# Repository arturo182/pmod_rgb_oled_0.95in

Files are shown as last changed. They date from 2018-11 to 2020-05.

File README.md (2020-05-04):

# 0.95" OLED PMOD

A tiny color OLED!

Perfect solution if you need a small display with vivid, high-contrast 16-bit color. PMOD connector can be used with FPGA and MCU dev boards

The display itself is a 0.95" color OLED, the resolution is 96x64 RGB pixels.

The display is driven by the SSD1331 IC, you can control it with a 4-wire write-only SPI. The board only supports 3.3V logic.

Libraries exist to interface the PMOD:
- [Arduino library](https://github.com/adafruit/Adafruit-SSD1331-OLED-Driver-Library-for-Arduino)
- [CircuitPython library](https://github.com/adafruit/Adafruit_CircuitPython_SSD1331)

**Note: This module is not 5V-tolerant!**

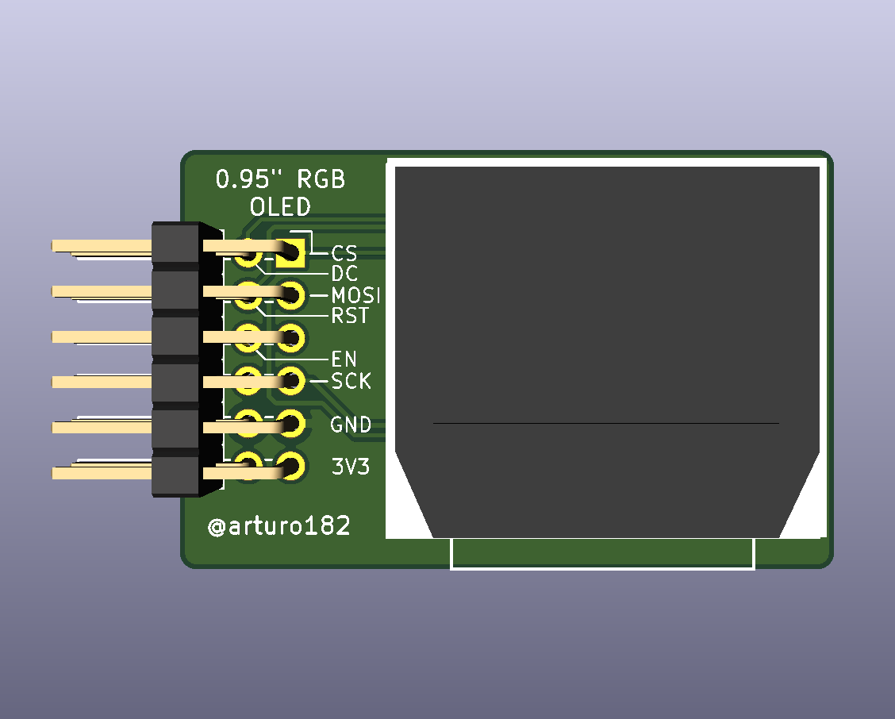
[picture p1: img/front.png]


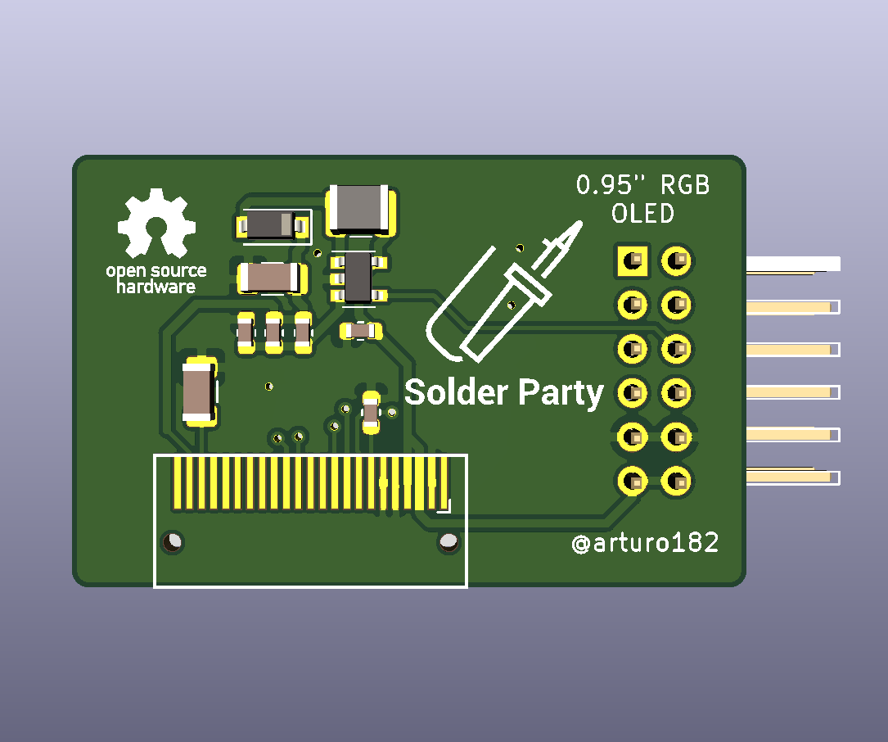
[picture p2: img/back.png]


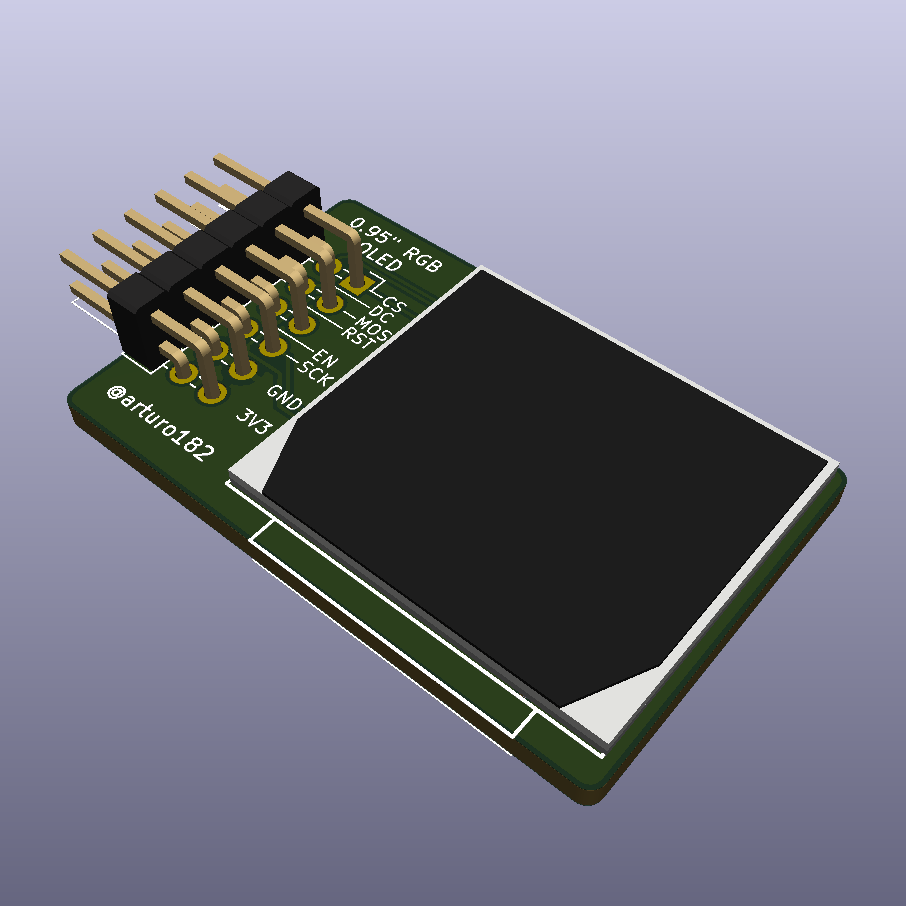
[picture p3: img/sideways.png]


Documentation licensed under the Creative Commons Attribution Share Alike 4.0 International License

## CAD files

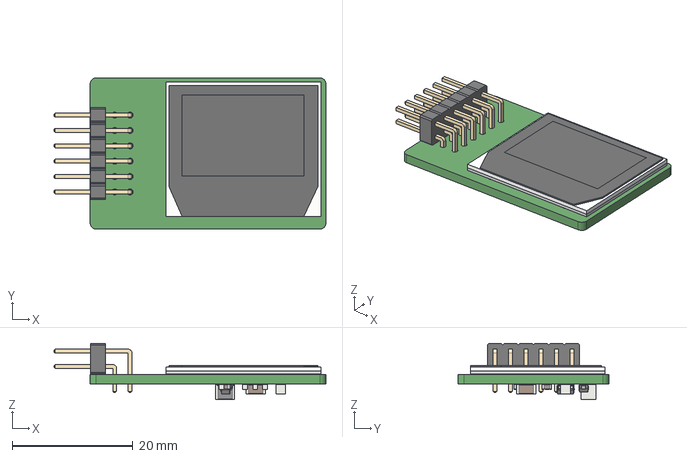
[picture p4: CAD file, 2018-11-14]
rgb_oled_0.95in.step
45.0 x 25.0 x 9.28 mm

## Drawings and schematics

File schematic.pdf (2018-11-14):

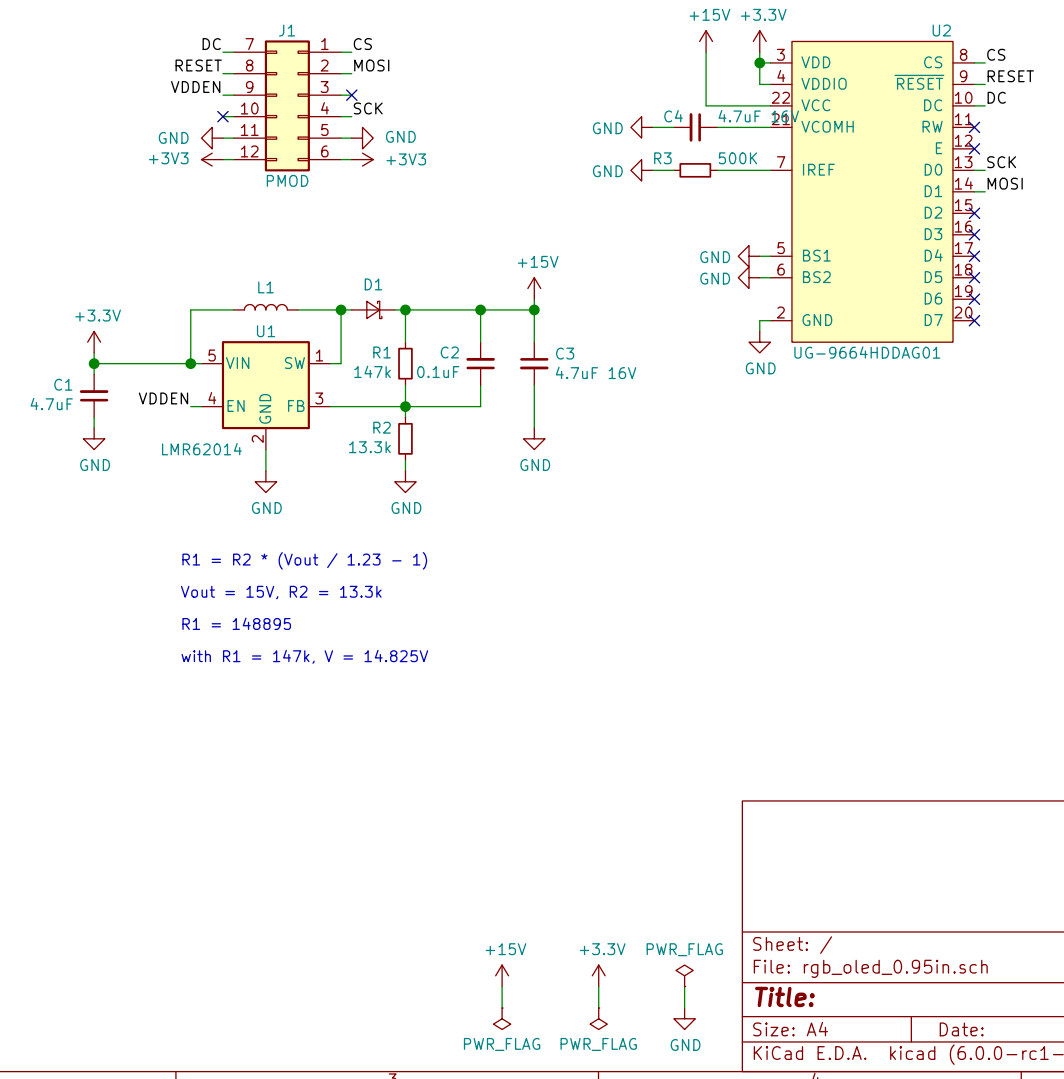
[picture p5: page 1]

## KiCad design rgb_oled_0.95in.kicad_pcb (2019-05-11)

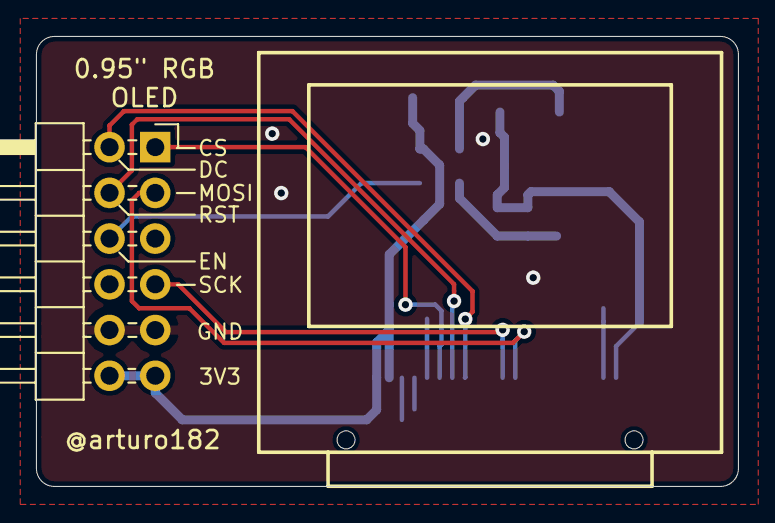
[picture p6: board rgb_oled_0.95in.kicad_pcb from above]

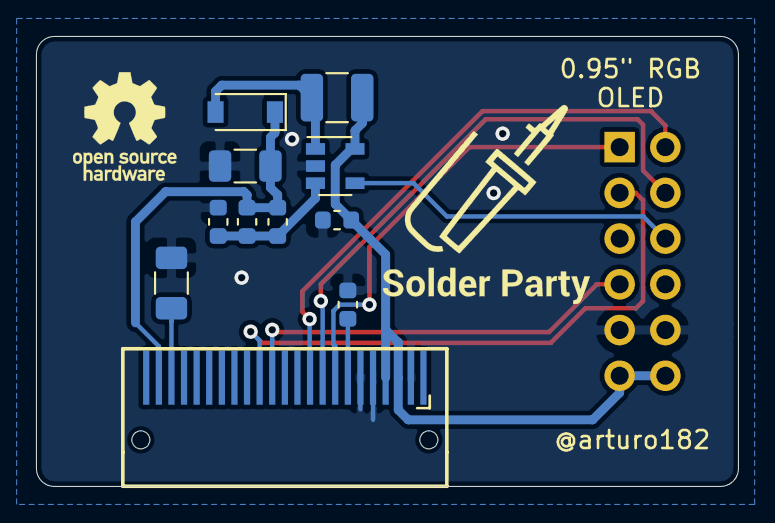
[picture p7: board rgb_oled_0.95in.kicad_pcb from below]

Board: 2 copper layers, 39.0 x 25.0 mm, 12 parts (10 on the bottom side), 13 nets.

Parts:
C1: 4.7uF; C_0603_1608Metric
C2: 0.1uF; C_0603_1608Metric
C3, C4: 4.7uF 16V; C_1206_3216Metric
D1: MBR0520LT1G; D_SOD-123
J1: PMOD; PMODHeader_2x06_P2.54mm_Horizontal
L1: 10uH, 0.48A; L_1210_3225Metric
R1: 147k; C_0603_1608Metric
R2: 13.3k; C_0603_1608Metric
R3: 510K; C_0603_1608Metric
U1: LMR62014; SOT-23-5
U2: UG-9664HDDAG01

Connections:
+3V3: C1.2, J1.6, J1.12, L1.1, U1.5, U2.3, U2.4
+15V: C2.2, C3.1, D1.1, R1.2, U2.22
/CS: J1.1, U2.8
/DC: J1.7, U2.10
/MOSI: J1.2, U2.14
/RESET: J1.8, U2.9
/SCK: J1.4, U2.13
/VDDEN: J1.9, U1.4
GND: C1.1, C3.2, C4.2, J1.5, J1.11, R2.1, R3.1, U1.2, U2.2, U2.5, U2.6
unnamed: C2.1, R1.1, R2.2, U1.3
unnamed: C4.1, U2.21
unnamed: D1.2, L1.2, U1.1
unnamed: R3.2, U2.7

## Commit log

2018-11-14 Initial import
    [rgb_oled_0.95in.kicad_pcb, rgb_oled_0.95in.sch, rgb_oled_0.95in.step]
2018-11-25 Add nicer silk
    [rgb_oled_0.95in.kicad_pcb, rgb_oled_0.95in.sch]
2018-11-25 Add bom
2019-05-11 Renamed bom, and schematic, added OLED 3d model
    [rgb_oled_0.95in.kicad_pcb]
